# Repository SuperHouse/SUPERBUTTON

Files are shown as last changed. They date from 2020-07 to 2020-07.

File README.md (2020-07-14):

"SuperButton" Assistive Technology Button
=========================================

Provides a simple dry-contact output assistive-technology
button using a load cell, so that the force required to activate
the button can be adjusted to suit the needs of the user.

The activation pressure can be adjusted by clicking the rotary
encoder and then rotating the encoder. Clicking the button again
applies the new setting and saves it in EEPROM. When it hasn't
been clicked into adjustment mode, the rotary encoder is ignored
so that it can't be accidentally bumped to a different setting.

The load cell reading is zeroed at startup, and can also be
re-zeroed by pressing the "tare" button.

The output duration can directly match the button press, or it
can be "stretched" to allow even a quick tap to cause a longer
beep output. The beep stretching switch activates this option.

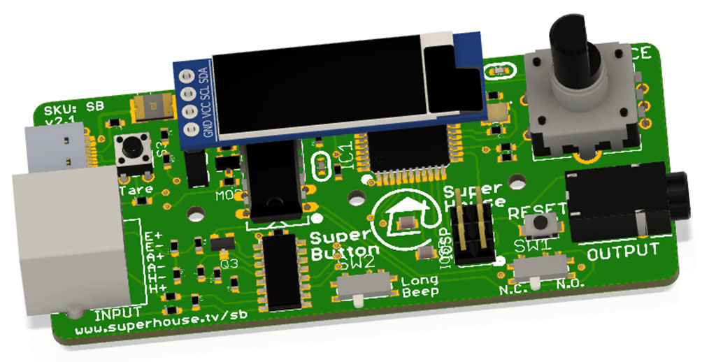
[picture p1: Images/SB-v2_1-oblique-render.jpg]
PCB render


Features:

 * 1 x input connection for a load-cell based button
 * 1 x USB connection for power or to emulate an input device
 * 1 x switched output (either N.O. or N.C.) to control other devices
 * 128x32 OLED to show current force reading and activation threshold
 * Rotary encoder to adjust activation threshold
 * "Tare" button to reset zero point
 * Pulse stretching feature controlled by slide switch

More information is available at:

  https://www.superhouse.tv/superbutton

Hardware
--------
The "Hardware" directory contains the PCB design as an EAGLE project.
EAGLE PCB design software is available from Autodesk free for
non-commercial use.

The PCB called "SUPERBUTTON" is the main controller which is mounted
in an enclosure.

The PCB called "SBCONN" is for the hand-held portion of the button, to
make assembly easier and improve connection reliability. It includes a
4.2mm hole for placement of an M3 clinch-nut, which can
be used to pass a travel-limit bolt through the PCB.

Firmware
--------
The "Firmware" directory contains example firmware as an Arduino
project.

Credits
-------
 * Jonathan Oxer <jon@oxer.com.au>
 * Chris Fryer <chris.fryer78@gmail.com>

License
-------
Copyright 2019-2020 SuperHouse Automation Pty Ltd  www.superhouse.tv  

The hardware portion of this project is licensed under the TAPR Open
Hardware License (www.tapr.org/OHL). The "license" folder within this
repository contains a copy of this license in plain text format.

The software portion of this project is licensed under the Simplified
BSD License. The "licence" folder within this project contains a
copy of this license in plain text format.

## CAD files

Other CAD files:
Production/SB-tcream-v3_0.dxf

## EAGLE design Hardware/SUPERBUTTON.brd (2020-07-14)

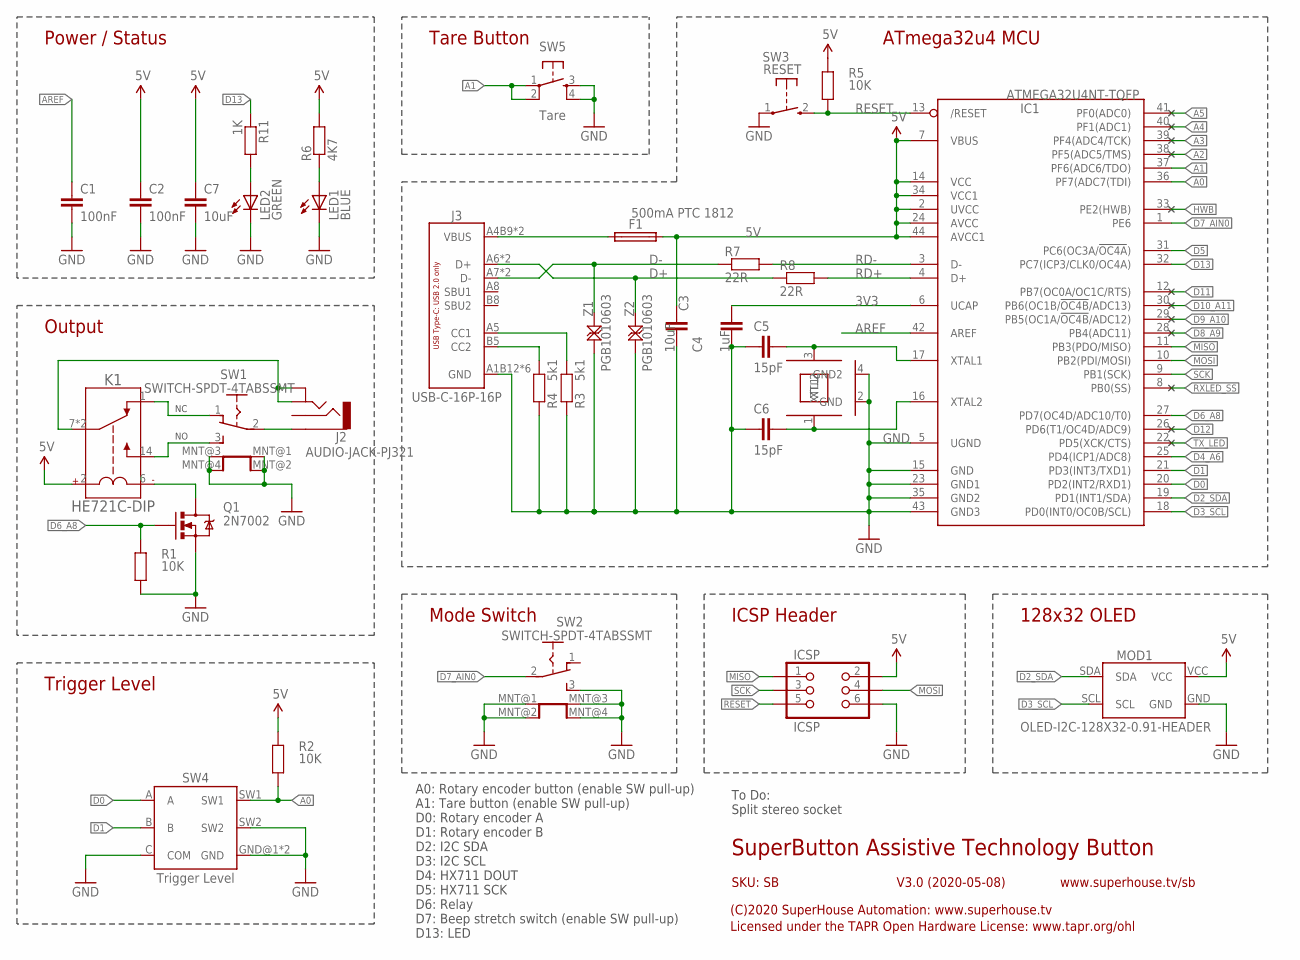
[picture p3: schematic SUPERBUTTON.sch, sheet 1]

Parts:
C1, C2: 100nF; C0603
C3, C7: 10uF; C0805
C4: 1uF; C0603
C5, C6: 15pF; C0603
F1: 500mA PTC 1812; 1812
IC1: ATMEGA32U4NT-TQFP; TQFP44
ICSP: ICSP; 2X03-ICSP
J2: AUDIO-JACK-PJ321
J3: USB-C-16P-16P; USB-C-16P
K1: HE721C-DIP; HE721
LED1: BLUE; LED-0603
LED2: GREEN; LED-0603
MOD1: OLED-I2C-128X32-0.91-HEADER; OLED-128X32-0.91-HEADER
Q1: 2N7002; SOT23-3
R1, R2, R5: 10K; R0603
R3, R4: 5k1; R0603
R6: 4K7; R0603
R7, R8: 22R; R0603
R11: 1K; R0603
SW1, SW2: SWITCH-SPDT-4TABSSMT; MK-12C02
SW3: RESET; TACTILE_SMT_3X4X2
SW4: Trigger Level; PEC12R
SW5: Tare; TACTILE-PTH-4.5MM
XTL1: 16MHz; CRYSTAL-SMD-3X2
Z1, Z2: PGB1010603; TVS0603

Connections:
3V3: C4.2, IC1.6 (UCAP)
5V: C2.1, C3.1, C7.1, F1.2, IC1.2 (UVCC), IC1.7 (VBUS), IC1.14 (VCC), IC1.24 (AVCC), IC1.34 (VCC1), IC1.44 (AVCC1), ICSP.2, K1.2 (COIL+), MOD1.VCC, R2.2, R5.2, R6.2; also elsewhere on the board
A0: IC1.36 (PF7(ADC7(TDI)), R2.1, SW4.SW1
A1: IC1.37 (PF6(ADC6/TDO)), SW5.1, SW5.2
A2: IC1.38 (PF5(ADC5/TMS))
A3: IC1.39 (PF4(ADC4/TCK))
A4: IC1.40 (PF1(ADC1))
A5: IC1.41 (PF0(ADC0))
AREF: C1.1, IC1.42 (AREF)
D0: IC1.20 (PD2(INT2/RXD1)), SW4.A
D1: IC1.21 (PD3(INT3/TXD1)), SW4.B
D2_SDA: IC1.19 (PD1(INT1/SDA)), MOD1.SDA
D3_SCL: IC1.18 (PD0(INT0/OC0B/SCL)), MOD1.SCL
D4_A6: IC1.25 (PD4(ICP1/ADC8)); also elsewhere on the board
D5: IC1.31 (PC6(OC3A/!OC4A!)); also elsewhere on the board
D6_A8: IC1.27 (PD7(OC4D/ADC10/T0)), Q1.1 (G), R1.2
D7_AIN0: IC1.1 (PE6), SW2.2 (COM)
D8_A9: IC1.28 (PB4(ADC11))
D9_A10: IC1.29 (PB5(OC1A/!OC4B!/ADC12))
D10_A11: IC1.30 (PB6(OC1B/!OC4B!/ADC13))
D11: IC1.12 (PB7(OC0A/OC1C/RTS))
D12: IC1.26 (PD6(T1/OC4D/ADC9))
D13: IC1.32 (PC7(ICP3/CLK0/OC4A)), R11.1
D+: J3.A6 (D+), J3.B6 (D+), R8.1, Z2.2
D-: J3.A7 (D-), J3.B7 (D-), R7.1, Z1.2
GND: C1.2, C2.2, C3.2, C4.1, C5.1, C6.1, C7.2, IC1.5 (UGND), IC1.15 (GND), IC1.23 (GND1), IC1.35 (GND2), IC1.43 (GND3), ICSP.6, J3.A1B12 (GND), J3.A12B1 (GND), J3.FIX1 (GND), J3.FIX2 (GND), J3.FIX3 (GND), J3.FIX4 (GND), LED1.C, LED2.C, MOD1.GND, Q1.2 (S), R1.1, R3.1, R4.1, SW1.MNT@1 (MNT), SW1.MNT@2 (MNT), SW1.MNT@3 (MNT), SW1.MNT@4 (MNT), SW2.3 (B), SW2.MNT@1 (MNT), SW2.MNT@2 (MNT), SW2.MNT@3 (MNT), SW2.MNT@4 (MNT), SW3.1, SW4.C (COM), SW4.GND@1 (GND), SW4.GND@2 (GND), SW4.SW2, SW5.3, SW5.4, XTL1.2 (GND), XTL1.4 (GND2), Z1.1, Z2.1; also elsewhere on the board
HWB: IC1.33 (PE2(HWB))
MISO: IC1.11 (PB3(PDO/MISO)), ICSP.1
MOSI: IC1.10 (PB2(PDI/MOSI)), ICSP.4
unnamed: LED2.A, R11.2
unnamed: K1.6 (COIL-), Q1.3 (D)
unnamed: K1.14 (NO), SW1.3 (B)
unnamed: LED1.A, R6.1
unnamed: K1.1 (NC), SW1.1 (A)
unnamed: J2.4A, J2.4B, K1.7 (COM), K1.8 (COM)
unnamed: J2.3, SW1.2 (COM)
unnamed: J3.B5 (CC2), R4.2
unnamed: C5.2, IC1.17 (XTAL1), XTL1.3 (XTL2)
unnamed: C6.2, IC1.16 (XTAL2), XTL1.1 (XTL1)
unnamed: J3.A5 (CC1), R3.2
RD+: IC1.4 (D+), R8.2
RD-: IC1.3 (D-), R7.2
RESET: IC1.13 (/RESET), ICSP.5, R5.1, SW3.2 (S)
RXLED_SS: IC1.8 (PB0(SS))
SCK: IC1.9 (PB1(SCK)), ICSP.3
TX_LED: IC1.22 (PD5(XCK/CTS))
USB+: F1.1, J3.A4B9 (VBUS), J3.A9B4 (VBUS)

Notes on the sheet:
ICSP Header
Tare Button
SuperButton Assistive Technology Button
V3.0 (2020-05-08)
SKU: SB
(C)2020 SuperHouse Automation: www.superhouse.tv
Licensed under the TAPR Open Hardware License: www.tapr.org/ohl
www.superhouse.tv/sb
Power / Status
Output
Trigger Level
128x32 OLED
A0: Rotary encoder button (enable SW pull-up) A1: Tare button (enable SW pull-up) D0: Rotary encoder A D1: Rotary encoder B D2: I2C SDA D3: I2C SCL D4: HX711 DOUT D5: HX711 SCK D6: Relay D7: Beep stretch switch (enable SW pull-up) D13: LED
To Do: Split stereo socket
Mode Switch
ATmega32u4 MCU

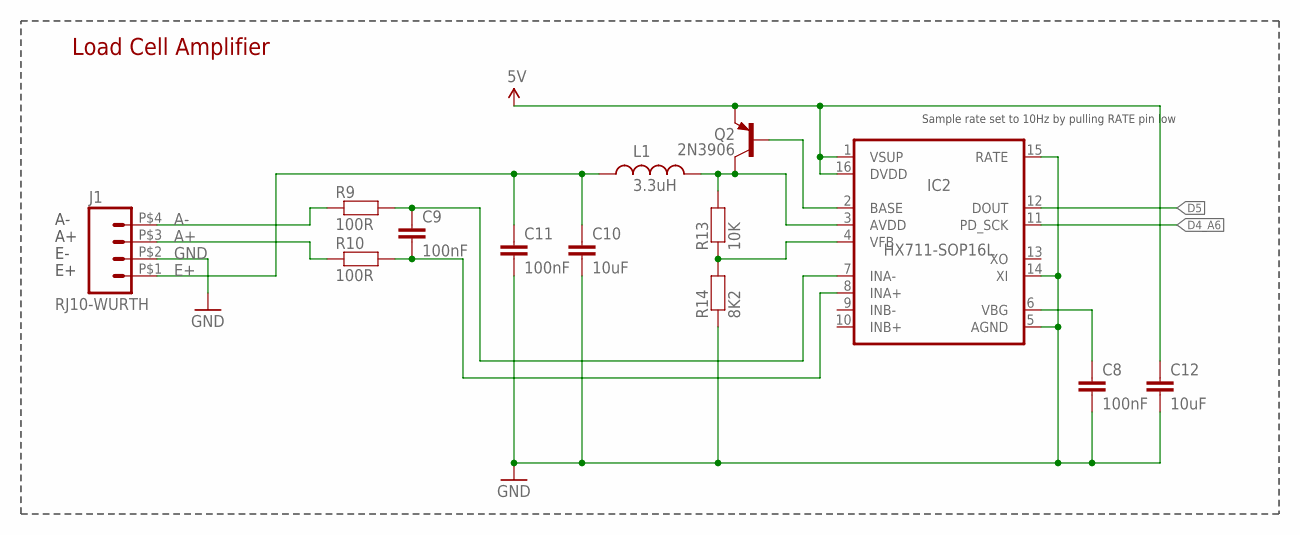
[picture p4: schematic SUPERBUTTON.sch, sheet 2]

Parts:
C8, C9, C11: 100nF; C0603
C10, C12: 10uF; C0805
IC2: HX711-SOP16L; SOP16-L
J1: RJ10-WURTH; RJ10
L1: 3.3uH; L0603
Q2: 2N3906; SOT23-BEC
R9, R10: 100R; R0603
R13: 10K; R0603
R14: 8K2; R0603

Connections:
5V: C12.1, IC2.1 (VSUP), IC2.16 (DVDD), Q2.E; also elsewhere on the board
A+: J1.P$3 (3), R10.1
A-: J1.P$4 (4), R9.1
D4_A6: IC2.11 (PD_SCK); also elsewhere on the board
D5: IC2.12 (DOUT); also elsewhere on the board
E+: C10.1, C11.1, J1.P$1 (1), L1.1
GND: C8.2, C10.2, C11.2, C12.2, IC2.5 (AGND), IC2.14 (XI), IC2.15 (RATE), J1.P$2 (2), R14.1; also elsewhere on the board
unnamed: C9.1, IC2.7 (INA-), R9.2
unnamed: C9.2, IC2.8 (INA+), R10.2
unnamed: IC2.3 (AVDD), L1.2, Q2.C, R13.2
unnamed: C8.1, IC2.6 (VBG)
unnamed: IC2.2 (BASE), Q2.B
unnamed: IC2.4 (VFB), R13.1, R14.2
XO: IC2.13 (XO)

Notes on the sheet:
Load Cell Amplifier
Sample rate set to 10Hz by pulling RATE pin low

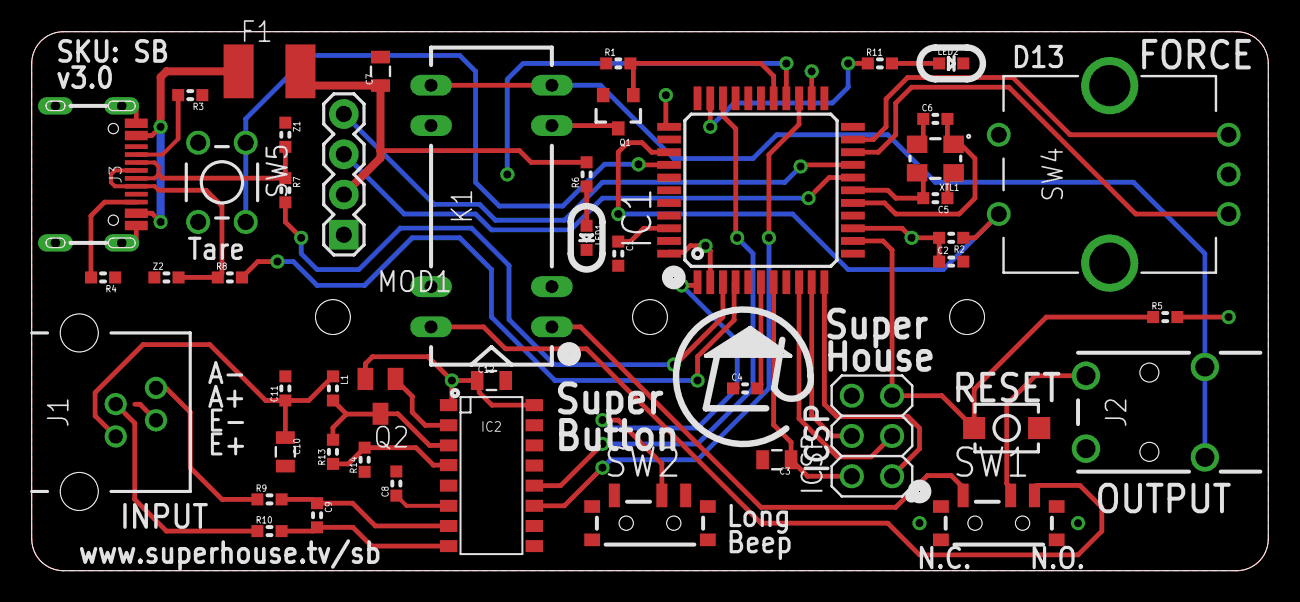
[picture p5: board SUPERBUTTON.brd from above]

Board: 2 copper layers, 78.0 x 34.0 mm, 47 parts (0 on the bottom side), 44 nets.

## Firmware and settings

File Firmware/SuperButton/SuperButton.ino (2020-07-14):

/**
   "SuperButton" Assistive Technology Button

   Provides a simple dry-contact output assistive-technology
   button using a load cell, so that the force required to activate
   the button can be adjusted to suit the needs of the user.

   The load cell reading is zeroed at startup, and can also be
   re-zeroed by pressing the "tare" button.

   The output duration can directly match the button press, or it
   can be "stretched" to allow even a quick tap to cause a longer
   beep output. The beep stretching switch activates this option.

   External dependencies. Install using Arduino library manager:
     "Adafruit GFX Library" by Adafruit
     "Adafruit SSD1306" by Adafruit
     "Encoder" library by Paul Stoffregen
     "HX711 Arduino Library" by Bogdan Necula, Andreas Motti

   More information:
     www.superhouse.tv/sb

   To do:
    - Require button press for 1 second to enter adjustment mode.
    - Missing button detection.

   Written by Chris Fryer and Jonathan Oxer for www.superhouse.tv
    https://github.com/superhouse/

   Copyright 2019-2020 SuperHouse Automation Pty Ltd www.superhouse.tv
*/
#define VERSION "3.0"
/*--------------------------- Configuration ------------------------------*/
// Configuration should be done in the included file:
#include "config.h"

/*--------------------------- Libraries ----------------------------------*/
// For load cell amplifier:
#include "HX711.h"
#include <Wire.h>
#include <Adafruit_GFX.h>
#include <Adafruit_SSD1306.h>
#include <Encoder.h>
#include <EEPROM.h>

/*--------------------------- Global Variables ---------------------------*/
// OLED:
uint32_t g_last_screen_update   = 0;

// Rotary encoder:
int32_t  g_old_encoder_position = -999;
uint32_t g_last_activity_time   = 0;
uint8_t  g_last_button_state    = 0;
uint8_t  g_current_button_state = 0;
uint32_t g_last_debounce_time   = 0;
uint16_t g_debounce_interval    = 500;

// Non-volatile memory:
uint32_t g_eeprom_address       = 0;

/* 227 (Pocophone) = 920000 */
// Load cell:
int32_t g_trigger_level         = DEFAULT_TRIGGER_LEVEL;
int32_t g_pressure_level        = 0;
uint8_t g_adjust_mode           = false;
uint8_t g_button_pressed        = false;
int32_t g_zero_pressure_offset  = 0;

// General:
uint32_t g_beep_start_time      = 0;
uint8_t  g_beep_stretch         = false;

/*--------------------------- Function Signatures ---------------------------*/
void checkIfThresholdReached();
void readPressureLevel();
int  getScaledLoadSensorValue();
void checkUiTimeout();
void readRotaryEncoder();
void updateOledDisplay();
void readLoadCell();
void checkModeButton();
void checkTareButton();
void checkBeepStretchSwitch();
void tareCellReading();

/*--------------------------- Instantiate Global Objects --------------------*/
// Load cell
HX711 scale;

// Rotary encoder
Encoder encoder(ENCODER_PIN_A, ENCODER_PIN_B);

// OLED display
Adafruit_SSD1306 display(128, 32, &Wire, -1);

/*--------------------------- Program ---------------------------------------*/
/**
  Setup
*/
void setup() {
  Serial.begin(SERIAL_BAUD_RATE);
  //while (!Serial) {
  //  ; // wait for serial port to connect. Needed for native USB port only
  //}
  Serial.print("SuperButton starting up, v");
  Serial.println(VERSION);

  pinMode(ENCODER_SWITCH,   INPUT_PULLUP);
  pinMode(ENCODER_PIN_A,    INPUT_PULLUP);
  pinMode(ENCODER_PIN_B,    INPUT_PULLUP);

  pinMode(TARE_BUTTON_PIN,  INPUT_PULLUP);
  pinMode(BEEP_STRETCH_PIN, INPUT_PULLUP);

  pinMode(LED_PIN,    OUTPUT);
  pinMode(OUTPUT_PIN, OUTPUT);

  // Load the trigger level from EEPROM if possible, or fall back to default
  EEPROM.get(g_eeprom_address, g_trigger_level);
  if (g_trigger_level < 1 || g_trigger_level > 100)
  {
    g_trigger_level = DEFAULT_TRIGGER_LEVEL;
  }

  // Initialize with the I2C addr 0x3C (for the 128x32)
  display.begin(SSD1306_SWITCHCAPVCC, 0x3C);
  display.clearDisplay();
  display.setTextSize(2);
  display.setTextColor(WHITE);
  display.setCursor(0, 0);
  display.println("Starting");
  display.print(" button");
  display.display();
  for (uint8_t i = 0; i < 3; i++)
  {
    delay(300);
    display.print(".");
    display.display();
  }

  scale.begin(LOADCELL_DOUT_PIN, LOADCELL_SCK_PIN);
  delay(400); // Load cell requires ~15ms to settle. Allow much longer for safety.

  // Do an automatic "tare" operation at startup
  tareCellReading();

  // We need a way to detect if the button isn't plugged in. Because the HX711
  // is internal, it always gives a reading. With no button it reads -1, but
  // that could be a legitimate tare offset so we cant just check for that.

  display.clearDisplay();
  display.setCursor(0, 10);
  display.println("  Ready");
  display.display();
  delay(1000);
}

/**
  Loop
*/
void loop()
{
  readPressureLevel();
  checkIfThresholdReached();
  checkUiTimeout();
  readRotaryEncoder();
  updateOledDisplay();
  checkModeButton();
  checkBeepStretchSwitch();
  checkTareButton();
}

/**
  See if the current reading from the load cell exceeds the trigger level
*/
void checkIfThresholdReached()
{
  if (g_pressure_level > g_trigger_level)
  {
    if (ENABLE_SERIAL_DEBUGGING)
    {
      //Serial.println("              ON");
    }
    digitalWrite(LED_PIN, HIGH);
    digitalWrite(OUTPUT_PIN, HIGH);
    g_last_activity_time = millis();
    g_beep_start_time = millis();
  } else {
    if (ENABLE_SERIAL_DEBUGGING)
    {
      //Serial.println();
    }
    if (((true == g_beep_stretch) && (millis() > g_beep_start_time + BEEP_STRETCH_PERIOD))
        || false == g_beep_stretch)
    {
      digitalWrite(LED_PIN, LOW);
      digitalWrite(OUTPUT_PIN, LOW);
    }
  }
}

/**
  See if the UI has timed out
*/
void checkUiTimeout()
{
  if (millis() - g_last_activity_time > (ADJUSTMENT_MODE_TIMEOUT * 1000))
  {
    g_adjust_mode = false;
  }
}

/**
  Check activity on the rotary encoder
*/
void readRotaryEncoder()
{
  int32_t new_encoder_position = 0;
  // Ignore the rotary encoder unless we're in adjustment mode
  if (true == g_adjust_mode)
  {
    new_encoder_position = (int)encoder.read() / 4; // Divide by 4 so we only get 1 step per detent
    if (new_encoder_position > g_old_encoder_position)
    {
      g_trigger_level++;
      g_last_activity_time = millis();
      // Prevent the trigger level going above 100%
      if (g_trigger_level > 100)
      {
        g_trigger_level = 100;
      }
      Serial.print("Trigger level: ");
      Serial.print(g_trigger_level);
      Serial.println("%");
      g_old_encoder_position = new_encoder_position;
    }
    if (new_encoder_position < g_old_encoder_position)
    {
      g_trigger_level--;
      g_last_activity_time = millis();
      // Prevent the trigger level going below 1%
      if (g_trigger_level < 1)
      {
        g_trigger_level = 1;
      }
      Serial.print("Trigger level: ");
      Serial.print(g_trigger_level);
      Serial.println("%");
      g_old_encoder_position = new_encoder_position;
    }
  } else {
    // Even if we don't want to read the encoder, consume the value
    // from it so that a queued change doesn't get applied the moment
    // we enter adjustment mode. We also use this to un-blank the
    // display if the knob is twiddled.
    new_encoder_position = (int)encoder.read() / 4; // Divide by 4 so we only get 1 step per detent
    if (new_encoder_position != g_old_encoder_position)
    {
      g_old_encoder_position = new_encoder_position;
      g_last_activity_time = millis();
      //Serial.println(new_encoder_position);
    }
  }
}

/**
  Draw current values on the OLED
*/
void updateOledDisplay()
{
  uint32_t time_now = millis();

  if (time_now - g_last_screen_update > SCREEN_UPDATE_INTERVAL)
  {
    g_last_screen_update = time_now;

    if (time_now - g_last_activity_time < (SCREEN_TIMEOUT_INTERVAL * 1000))
    {
      // The screen hasn't timed out yet, so display stuff
      // Display the current pressure level
      display.clearDisplay();
      display.setTextSize(4);
      //display.setTextFont(6);
      display.cp437(true);
      display.setTextColor(WHITE, BLACK);
      display.setCursor(0, 2);
      display.println(g_pressure_level);

      // Dividing line between numbers
      display.drawLine(67, 0, 67, 31, WHITE);

      // Display the trigger level
      display.setTextSize(3);
      if (true == g_adjust_mode)
      {
        display.setTextColor(BLACK, WHITE);
        display.fillRect(67, 0, 127, 32, WHITE);
      } else {
        display.setTextColor(WHITE);
      }
      display.setCursor(73, 5);
      display.println(g_trigger_level);
      display.display();
      if (ENABLE_SERIAL_DEBUGGING)
      {
        //Serial.println("Show");
      }
    } else {
      // The screen has timed out, so blank it
      display.clearDisplay();
      display.display();
      if (ENABLE_SERIAL_DEBUGGING)
      {
        //Serial.println("Blank");
      }
    }
  }
}

/**
  Read the current pressure level
*/
void readPressureLevel()
{
  g_pressure_level = getScaledLoadCellValue() + g_zero_pressure_offset;
  if (ENABLE_SERIAL_DEBUGGING)
  {
    //Serial.println(g_pressure_level);
  }
}

/**
  Read the load cell and scale the value to a percentage
*/
int32_t getScaledLoadCellValue()
{
  int32_t pressure;
  if (scale.is_ready())
  {
    int32_t pressure_reading = scale.read() * -1;
    pressure = map(pressure_reading, 0, 1000000, 0, 100);
  } else {
    //Serial.println("HX711 not found.");
  }
  return pressure;
}

/**
  See if the rotary encoder button has been pressed
*/
void checkModeButton()
{
  g_last_button_state = g_current_button_state;
  g_current_button_state = digitalRead(ENCODER_SWITCH);

  // Transition from unpressed to pressed
  if (LOW == g_current_button_state && HIGH == g_last_button_state)
  {
    g_last_activity_time = millis();  // Used to un-blank display

    // If we haven't waited long enough then ignore this press
    if (millis() - g_last_debounce_time <= g_debounce_interval) {
      return;
    }

    Serial.print("Button pressed.");
    g_last_debounce_time = millis();

    if (true == g_adjust_mode)
    {
      g_adjust_mode = false;
      Serial.println(" Locking screen.");
      EEPROM.put(g_eeprom_address, g_trigger_level);
      Serial.print("Saving trigger level: ");
      Serial.print(g_trigger_level);
      Serial.println("%");
    } else {
      g_adjust_mode = true;
      Serial.println(" Unlocking screen.");
    }
  }
}

/**
  Check the position of the beep stretch switch
*/
void checkBeepStretchSwitch()
{
  uint8_t switch_position;
  switch_position = digitalRead(BEEP_STRETCH_PIN);

  if (LOW == switch_position)
  {
    g_beep_stretch = true;
  } else {
    g_beep_stretch = false;
  }
}

/**
  Check if the tare button is pressed
*/
void checkTareButton()
{
  uint8_t switch_position;
  switch_position = digitalRead(TARE_BUTTON_PIN);

  if (LOW == switch_position)
  {
    // Button is pressed, do the tare!
    delay(200);
    tareCellReading();
    delay(100);
  }
}

/**
  Reset the zero position of the load cell
*/
void tareCellReading()
{
  // Read the load cell to set the zero offset
  g_zero_pressure_offset = -1 * getScaledLoadCellValue();
#if ENABLE_SERIAL_DEBUGGING
  Serial.print("Tare offset: ");
  Serial.println(g_zero_pressure_offset, DEC);
#endif
}

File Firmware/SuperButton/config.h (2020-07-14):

/* ----------------- General Config -------------------------------- */
#define DEFAULT_TRIGGER_LEVEL       50   // % of full pressure. Replaced by value from EEPROM
#define ADJUSTMENT_MODE_TIMEOUT     20   // Seconds
#define SCREEN_TIMEOUT_INTERVAL     30   // Seconds
#define SCREEN_UPDATE_INTERVAL     200   // 200ms = 5 updates per second

#define BEEP_STRETCH_PERIOD       2000   // ms

/* Serial */
#define ENABLE_SERIAL_DEBUGGING  true   // true / false
#define SERIAL_BAUD_RATE          9600   // Speed for USB serial console

/* ----------------- Hardware-specific Config ---------------------- */
/* Rotary encoder */
#define ENCODER_PIN_A       1            // Input pullup applied
#define ENCODER_PIN_B       0            // Input pullup applied
#define ENCODER_SWITCH     A0            // Input pullup applied
#define DEBOUNCE_PERIOD   500            // ms

/* Inputs */
#define TARE_BUTTON_PIN    A1
#define BEEP_STRETCH_PIN    7

/* Load cell */
#define LOADCELL_SCK_PIN    4            // HX711 Sck
#define LOADCELL_DOUT_PIN   5            // HX711 Dout

/* Output */
#define OUTPUT_PIN          6            // Controls relay
#define LED_PIN            13            // Controls internal LED

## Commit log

2020-03-05 Major rework for Barr Group guidelines and fix OLED refresh bug
    [SuperButton.ino, config.h]
2020-04-16 Divide encoder output by 4 for 1 step per detent; new button code
2020-05-08 Major update for v3.0 release with new hardware: * Remove haptic feedback * Add "tare" button * Add "beep stretching" switch
2020-07-06 Replaced capacitors to simplify BOM for production
    [SB.brd, SB.sch]
2020-07-14 Moved files into subdirectory prior to merging
    [SB-tcream-v3_0.dxf, SB.brd, SB.sch]
2020-07-14 File cleanup
    [SB-tcream-v3_0.dxf]
2020-07-14 Renamed PCB files
    [SUPERBUTTON.brd, SUPERBUTTON.sch]
2020-07-14 Merged button PCB into main project
    [SBCONN.brd, SBCONN.sch]

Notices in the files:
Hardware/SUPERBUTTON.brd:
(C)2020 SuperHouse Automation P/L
